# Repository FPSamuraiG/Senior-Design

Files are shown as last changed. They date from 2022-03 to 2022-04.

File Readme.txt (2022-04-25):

An Electronic Enrichment System for Saltwater Animal Enclosures

University of Cincinnati
CEAS
EE/ELTN Senior Design
April 2022

Team Members:
  Chris Dombrosky
  Brandon Carroll
  Nathaniel Collum
  Hayden Lampert

Advisors:
  Dr. Dieter Vanderelst
  Dr. Katie Kalafut
  
This repository contains code, PCB files, 3D models, and documentation for this senior design project.

3D Models: Contains 3D models for the project's pushbutton enclosure and wireless charging pad as .step files. Also contains .stl files for 3D printing these components.

Datasheets: Contains manufacturer datasheets for key project components.

PDB Files: Contains EAGLE files for the projects PCBs. Also contains an EAGLE library for custom components used on the PCBs, zipped gerber files for manufacturing additional copies, and component lists for the PCBs.

Release: Contains the .hex file for programming the microcontroller used in this project.

Senior_Design.X: MPLAB X IDE project folder for the microcontroller code. Can be opened as a project in MPLAB X IDE with MPLAB Code Configurator installed.

Project Abstract:

In this project, we designed a prototype input collection system for use in interactive electronic systems in saltwater animal enclosures. Increasing interactivity in enclosures has the potential to improve animal welfare and allow for research and behavior monitoring. Implementing an input device underwater is made difficult by the lack of premade input devices that function underwater, waterproofing requirements, and the ineffectiveness of wireless communication methods underwater. To address these challenges, we designed a prototype input system that includes a custom submersible pushbutton, fiber optic communication, wirelessly rechargeable battery, and extensive waterproofing features. This prototype functions as a pushbutton that can be installed underwater and connected to an Arduino through a fiber optic cable. It provides a tactile input for animals while maintaining safety by not exposing wires or electronics to water. Although it only functions as a pushbutton in its current state, this prototype was designed to be easy to use and easy to add additional sensors or input devices to. Overall, it meets the basic needs presented by our advisors while also making future work and improvements easier.

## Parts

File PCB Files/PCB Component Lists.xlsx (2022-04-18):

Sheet: Control PCB
Label | Description | Value | Package | Required?
C1 | Microcontroller decoupling capacitor | 0.1uF | 1206 SMD | Required
C2 | MCLR Pin Capacitor (See 4.3 of PIC18F16Q41 Datasheet) | 0.1uF | 1206 SMD | Required
C5 | Voltage regulator decoupling capacitor | 0.1uF | 1206 SMD | Required
C6 | Voltage regulator decoupling capacitor | 0.1uF | 1206 SMD | Required
D1 | Fiber Optic Transmitter (TOTX1350 or equivalent) | n/a | Unique | Required
J1 | Programming connector (0.1" Pitch 5 pin male header) | n/a | 0.1" Pitch TH | Required
J2 | I/O pin connector (0.1" Pitch 6 pin female header) | n/a | 0.1" Pitch TH | Optional
J3 | Battery connector (0.1" Pitch 6 pin female header) | n/a | 0.1" Pitch TH | Optional
J4 | I/O pin connector (0.1" Pitch 6 pin female header) | n/a | 0.1" Pitch TH | Optional
J5 | I/O pin connector (0.1" Pitch 5 pin female header) | n/a | 0.1" Pitch TH | Optional
JP1 | MCLR capacitor solder jumper (See 4.3 of PIC18F16Q41 Datasheet) | n/a | SMD | Required
R1 | MCLR pullup resistor (See 4.3 of PIC18F16Q41 Datasheet) | 10kΩ | 1206 SMD | Required
R2 | MCLR current limiting resistor (See 4.3 of PIC18F16Q41 Datasheet) | 470kΩ | 1206 SMD | Required
R3 | Fiber transmitter curent limiting resistor (See TOTX1353 datasheet) | 1kΩ | 1206 SMD | Required
R4 | I/O optional pullup resistor | 10kΩ | 1206 SMD | Optional
R5 | I/O optional pullup resistor | 10kΩ | 1206 SMD | Optional
R6 | I/O optional pullup resistor | 10kΩ | 1206 SMD | Optional
R7 | I/O optional pullup resistor | 10kΩ | 1206 SMD | Optional
R8 | Fuel gauge alert pullup resistor | 10kΩ | 1206 SMD | Optional
R9 | I2C SCL line pullup resistor | 2.2kΩ | 1206 SMD | Required
R10 | I2C SDA line pullup resistor | 2.2kΩ | 1206 SMD | Required
R11 | I/O optional pullup resistor | 10kΩ | 1206 SMD | Optional
R12 | I/O optional pullup resistor | 10kΩ | 1206 SMD | Optional
R13 | I/O optional pullup resistor | 10kΩ | 1206 SMD | Optional
R14 | I/O optional pullup resistor | 10kΩ | 1206 SMD | Optional
R15 | Reed switch pullup resistor | 10kΩ | 1206 SMD | Required
R16 | I/O optional pullup resistor | 10kΩ | 1206 SMD | Optional
R17 | I/O optional pullup resistor | 10kΩ | 1206 SMD | Optional
IC1 | PIC18F16Q41 microcontroller | n/a | 20 DIP/DIL | Required
U1 | AP2138N-3.3TRG1 linear voltage regulator (3.3V out) | n/a | SOT23-3 | Required

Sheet: Receiver PCB
Label | Description | Value | Package | Required?
U1 | Fiber Optic Receiver (TORX1355 or equivalent) | n/a | Unique | Required
U2 | Hex Inverter (SN74HC04 or equivalent) | n/a | PDIP-14 | Required
C1 | Capacitor | 0.1 uF | 1206 SMD | Required
J1 | Header (0.1" Pitch 5 pin female header) | n/a | 0.1" Pitch TH | Required

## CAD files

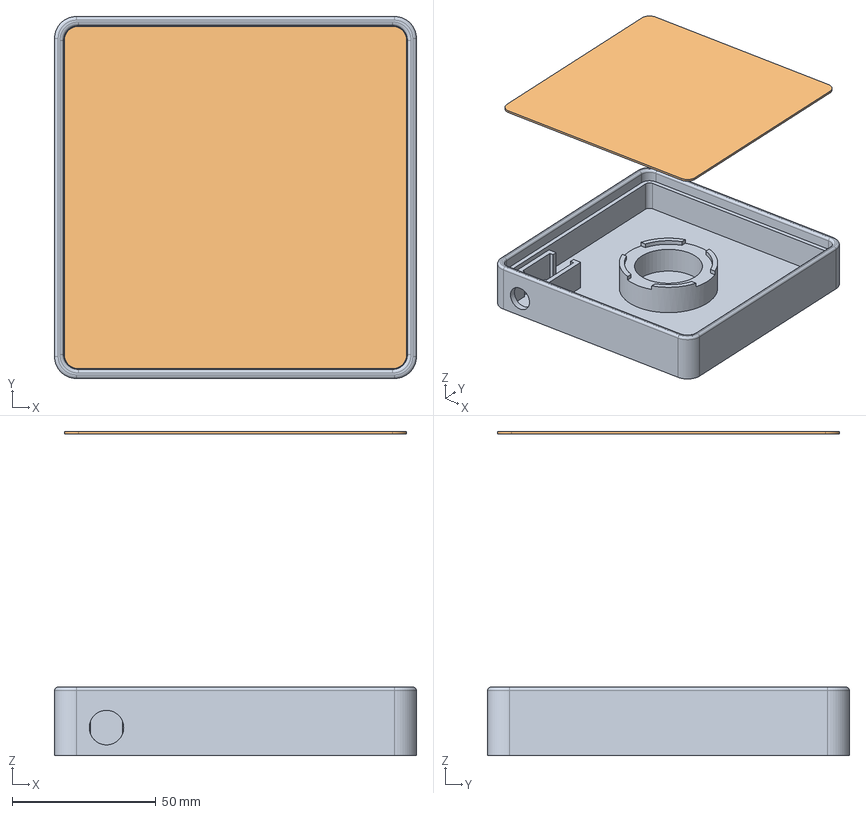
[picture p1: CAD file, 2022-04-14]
3D Models/Charging Tray.step
125.8 x 125.8 x 112.7 mm

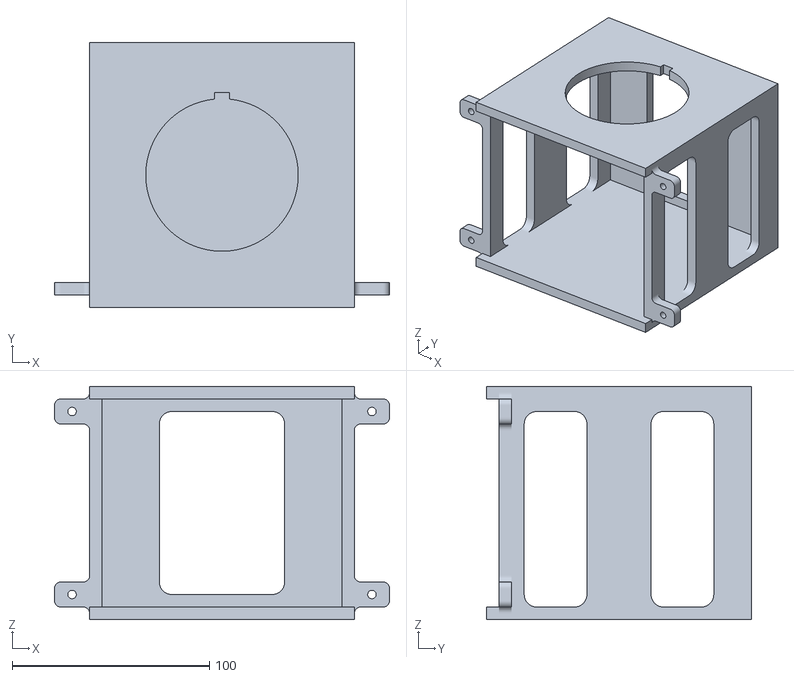
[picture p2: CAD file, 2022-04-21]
3D Models/STL Files/Shell.stl
169.7 x 134.1 x 118.1

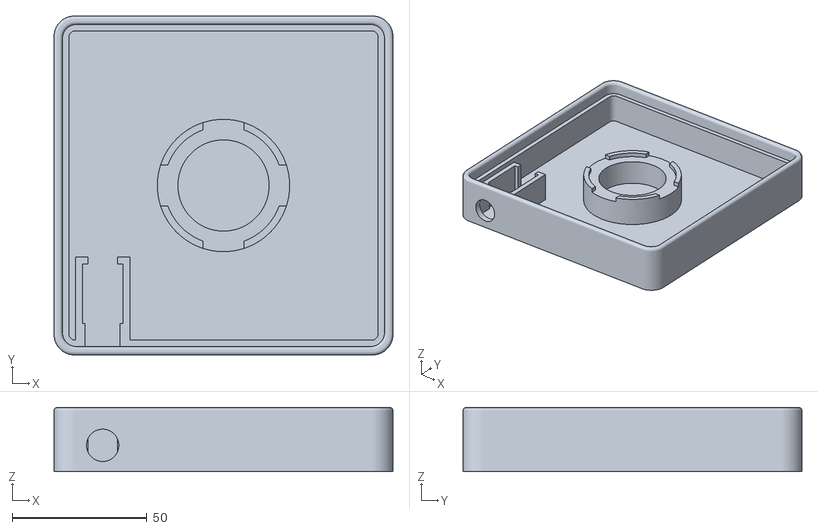
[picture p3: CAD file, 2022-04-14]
3D Models/STL Files/Tray.stl
125.8 x 125.8 x 23.9

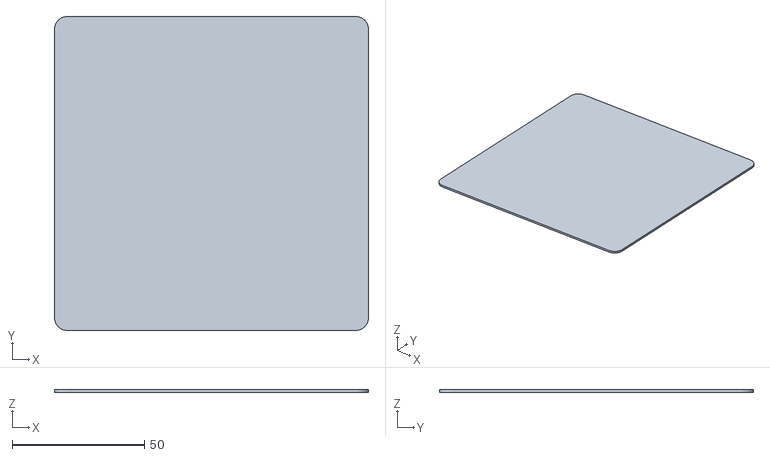
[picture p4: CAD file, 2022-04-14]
3D Models/STL Files/Plate.stl
118.9 x 118.9 x 1.00

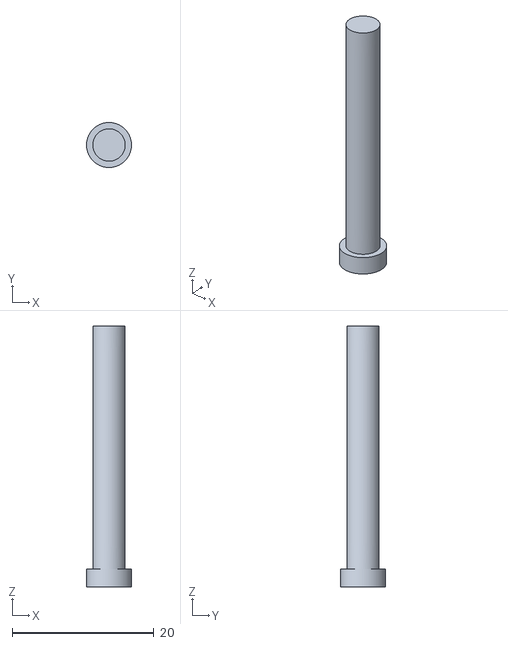
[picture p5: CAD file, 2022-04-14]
3D Models/STL Files/Spring Support.stl
6.35 x 6.35 x 36.8

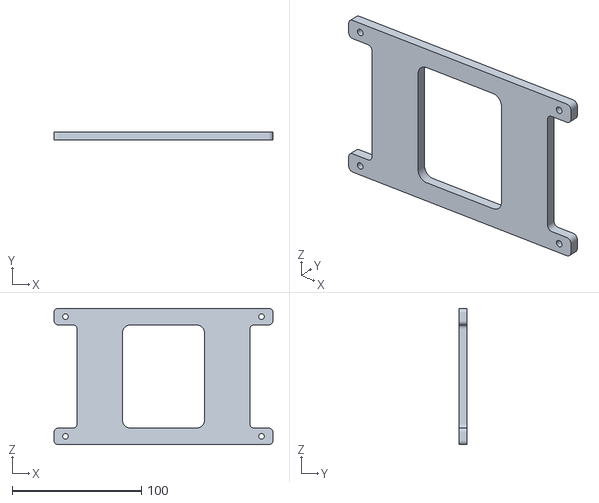
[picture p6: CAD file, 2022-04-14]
3D Models/STL Files/Wall.stl
169.7 x 6.35 x 105.4

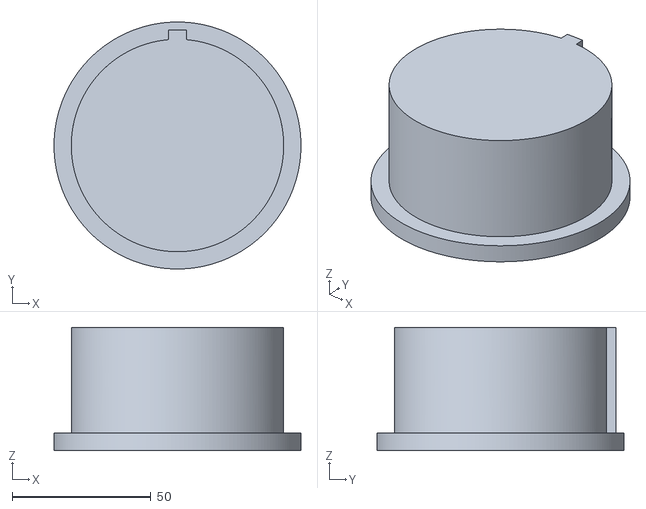
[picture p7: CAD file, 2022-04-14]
3D Models/STL Files/Button.stl
88.9 x 88.9 x 44.5

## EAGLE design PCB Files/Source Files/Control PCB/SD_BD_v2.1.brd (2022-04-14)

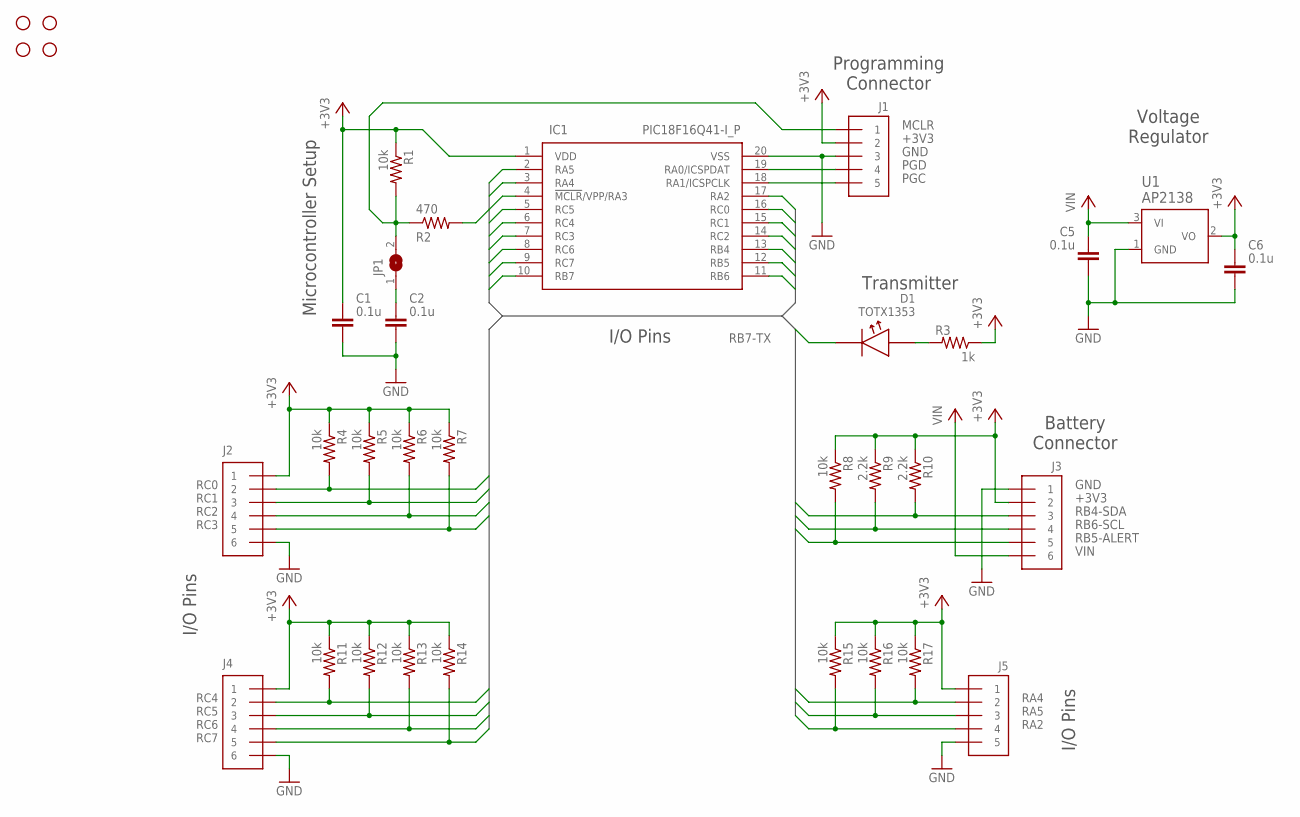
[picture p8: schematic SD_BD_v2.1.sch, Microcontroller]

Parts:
C1, C2, C5, C6: 0.1u; CAPC3216X135
D1: TOTX1353; TOXX1353
H1, H2, H3, H4: STAND-OFF
IC1: PIC18F16Q41-I_P; DIP794W56P254L2591H533Q20N
J1: M20-9990546; HDR-5-M
J2, J3, J4: PPTC061LFBN-RC; HDR-6-F
J5: PPTC051LFBN-RC; HDR-5-F
JP1: SJ
R1, R4, R5, R6, R7, R8, R11, R12, R13, R14, R15, R16, R17: 10k; R1206
R2: 470; R1206
R3: 1k; R1206
R9, R10: 2.2k; R1206
U1: AP2138N-3.3TRG1IC3_AP2138N-3.3TRG1_DIO-M; IC3_AP2138N-3.3TRG1_DIO-M

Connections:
+3V3: C1.1, C6.1, IC1.1 (VDD), J1.2, J2.1, J3.2, J4.1, J5.1, R1.1, R3.1, R4.1, R5.1, R6.1, R7.1, R8.1, R9.1, R10.1, R11.1, R12.1, R13.1, R14.1, R15.1, R16.1, R17.1, U1.2 (VO)
GND: C1.2, C2.2, C5.2, C6.2, IC1.20 (VSS), J1.3, J2.6, J3.1, J4.6, J5.5, U1.1 (GND)
MCLR: J1.1, JP1.2, R1.2, R2.1
unnamed: D1.3 (A), R3.2
unnamed: IC1.4 (!MCLR!/VPP/RA3), R2.2
unnamed: C2.1, JP1.1
PGC: IC1.18 (RA1/ICSPCLK), J1.5
PGD: IC1.19 (RA0/ICSPDAT), J1.4
RA2: IC1.17 (RA2), J5.4, R15.2
RA4: IC1.3 (RA4), J5.2, R17.2
RA5: IC1.2 (RA5), J5.3, R16.2
RB4-SDA: IC1.13 (RB4), J3.3, R10.2
RB5-ALERT: IC1.12 (RB5), J3.5, R8.2
RB6-SCL: IC1.11 (RB6), J3.4, R9.2
RB7-TX: D1.2 (K), IC1.10 (RB7)
RC0: IC1.16 (RC0), J2.2, R4.2
RC1: IC1.15 (RC1), J2.3, R5.2
RC2: IC1.14 (RC2), J2.4, R6.2
RC3: IC1.7 (RC3), J2.5, R7.2
RC4: IC1.6 (RC4), J4.2, R11.2
RC5: IC1.5 (RC5), J4.3, R12.2
RC6: IC1.8 (RC6), J4.4, R13.2
RC7: IC1.9 (RC7), J4.5, R14.2
VIN: C5.1, J3.6, U1.3 (VI)

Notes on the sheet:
I/O Pins
Transmitter
Microcontroller Setup
Voltage Regulator
Programming Connector
Battery Connector

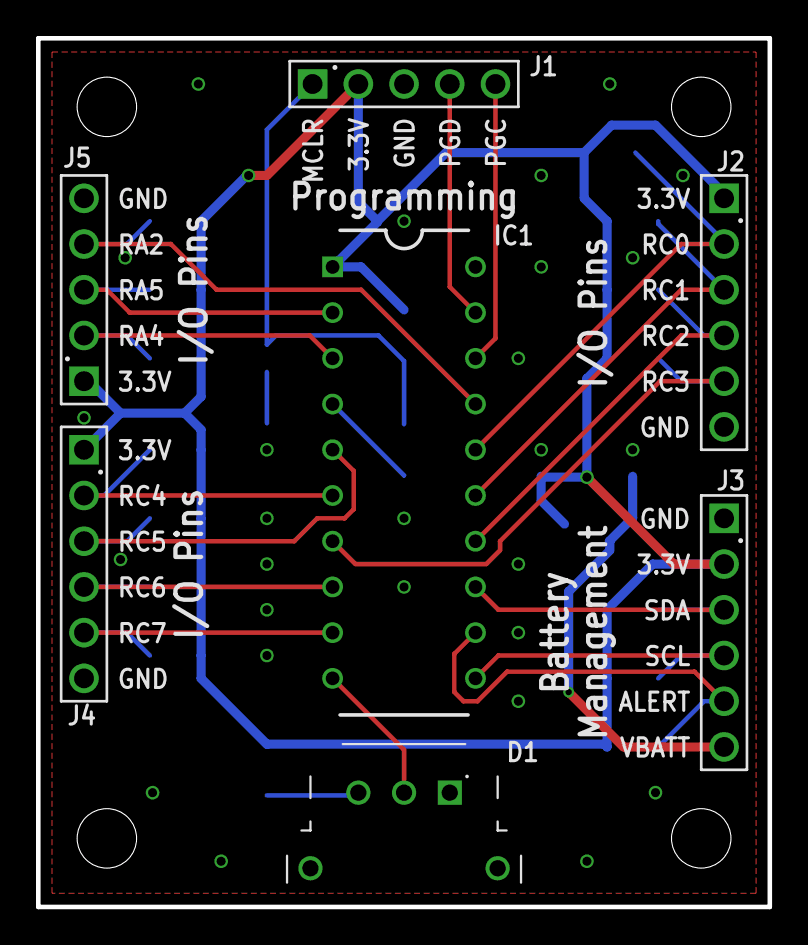
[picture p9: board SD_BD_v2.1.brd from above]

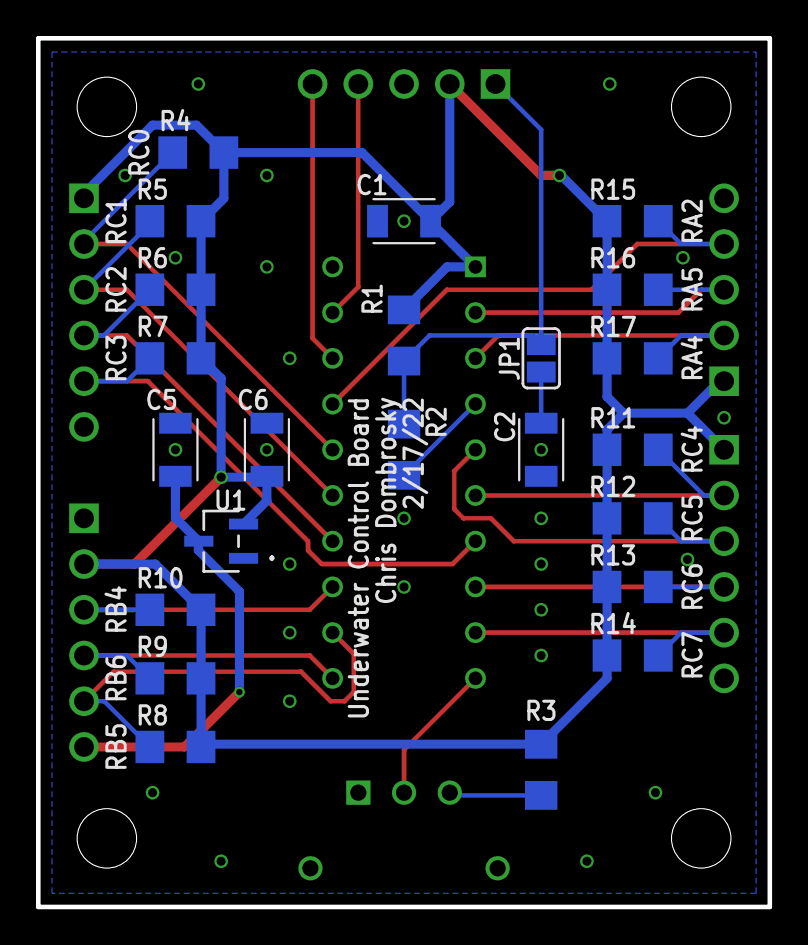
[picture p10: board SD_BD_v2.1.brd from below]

Board: 2 copper layers, 40.6 x 48.3 mm, 34 parts (23 on the bottom side), 24 nets.

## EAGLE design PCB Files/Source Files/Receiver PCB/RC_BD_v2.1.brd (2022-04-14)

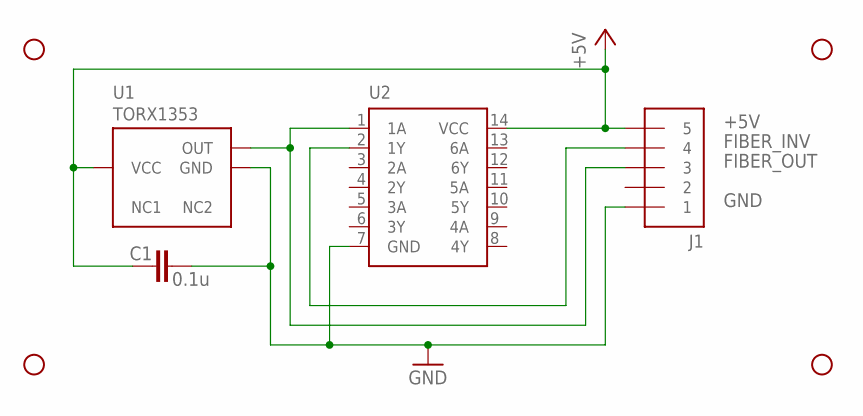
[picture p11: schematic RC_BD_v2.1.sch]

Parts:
C1: 0.1u; CAPC3216X135
H1, H2, H3, H4: STAND-OFF
J1: PPTC051LFBN-RC; HDR-5-F
U1: TORX1353; TOXX1353
U2: SN74HC04AN; DIL14

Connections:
+5V: C1.1, J1.5, U1.3 (VCC), U2.14 (VCC)
FIBER_INV: J1.4, U2.2 (1Y)
FIBER_OUT: J1.3, U1.1 (OUT), U2.1 (1A)
GND: C1.2, J1.1, U1.2 (GND), U2.7 (GND)

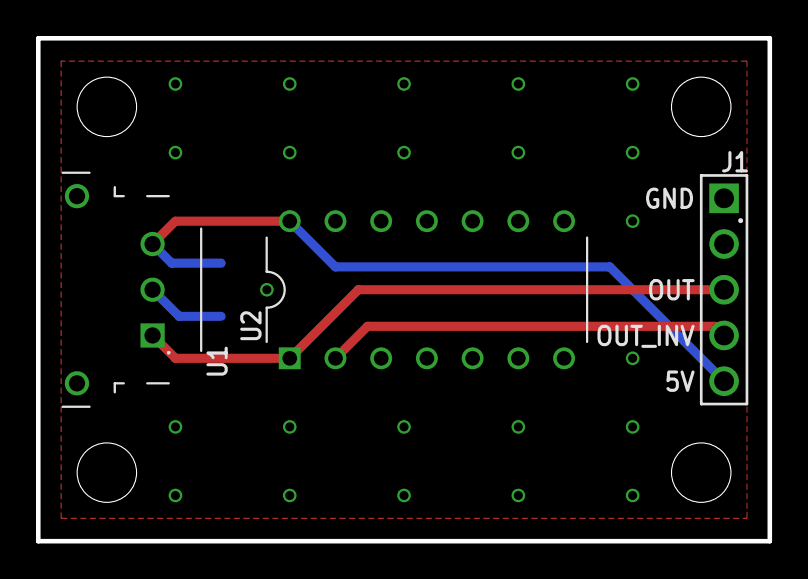
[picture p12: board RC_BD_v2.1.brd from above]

Board: 2 copper layers, 40.6 x 27.9 mm, 8 parts (1 on the bottom side), 4 nets.

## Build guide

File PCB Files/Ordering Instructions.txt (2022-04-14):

To Order Additional PCBs
	1) Upload zip files from the "Zipped Gerber Files" folder to JLCPCB
	2) Choose quantity and manufacturing options and order bare boards
	3) Order the electronic components listed in the "PCB Component Lists" spreadsheet
		3a) Order components from suppliers such as DigiKey or Mouser based on lowest price
		3b) For passives (resistors, capacitors) make sure to order the correct value and package for each component
		3c) For ICs and fiber optic components, order the same parts as in the spreadsheet if possible but choose an equivalent part based on data sheets if any component is unavailable
		3d) For headers only gender, number of pins, and pitch matter
	4) Receive components and solder

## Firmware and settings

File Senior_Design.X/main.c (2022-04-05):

/**
  Generated Main Source File

  Company:
    Microchip Technology Inc.

  File Name:
    main.c

  Summary:
    This is the main file generated using PIC10 / PIC12 / PIC16 / PIC18 MCUs

  Description:
    This header file provides implementations for driver APIs for all modules selected in the GUI.
    Generation Information :
        Product Revision  :  PIC10 / PIC12 / PIC16 / PIC18 MCUs - 1.81.7
        Device            :  PIC18F16Q41
        Driver Version    :  2.00
*/

/*
    (c) 2018 Microchip Technology Inc. and its subsidiaries. 
    
    Subject to your compliance with these terms, you may use Microchip software and any 
    derivatives exclusively with Microchip products. It is your responsibility to comply with third party 
    license terms applicable to your use of third party software (including open source software) that 
    may accompany Microchip software.
    
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
    IN NO EVENT WILL MICROCHIP BE LIABLE FOR ANY INDIRECT, SPECIAL, PUNITIVE, 
    INCIDENTAL OR CONSEQUENTIAL LOSS, DAMAGE, COST OR EXPENSE OF ANY KIND 
    WHATSOEVER RELATED TO THE SOFTWARE, HOWEVER CAUSED, EVEN IF MICROCHIP 
    HAS BEEN ADVISED OF THE POSSIBILITY OR THE DAMAGES ARE FORESEEABLE. TO 
    THE FULLEST EXTENT ALLOWED BY LAW, MICROCHIP'S TOTAL LIABILITY ON ALL 
    CLAIMS IN ANY WAY RELATED TO THIS SOFTWARE WILL NOT EXCEED THE AMOUNT 
    OF FEES, IF ANY, THAT YOU HAVE PAID DIRECTLY TO MICROCHIP FOR THIS 
    SOFTWARE.
*/

#include <stdio.h>
#include "mcc_generated_files/mcc.h"
#include "comm_uart.h"
#include "sleep.h"
#include "battery.h"

/*
                         Main application
 */
void main(void)
{
    // Initialize the device
    SYSTEM_Initialize();
    TMR0_StopTimer();
    sleep_setup();
    IOCAF2_SetInterruptHandler(btn_interrupt);
    TMR0_SetInterruptHandler(tmr_interrupt);
    INTERRUPT_GlobalInterruptEnable();
    
    //Startup procedure
    __delay_ms(100);
    uart_send_string("\nUnderwater Input Platform\r\n");
    uart_send_string("Version 0.20\t(3/6/2022)\r\n\n");
    
    int SOC; //Battery charge level;
 
    int start_btn_state; //State of pushbutton at start of loop, used to see if
                         //the button changed states during loop execution
    int last_btn_state_sent = 1;  //State of button when a message was last sent, used to
                             //avoid sending consecutive button states in situations
                             //like button bouncing.
    int btn_position = 0;
    
    char batt_msg[7]; //Battery message
    char btn_msg[7];  //Button message
    while (1)
    {
        //Save state of pushbutton at loop start
        __delay_ms(1);
        start_btn_state = btn_state;
        
        //Check if button is in same state after a delay to debounce
        __delay_ms(50);
        if(btn_state == start_btn_state) {
            input_handled = 1;
            
            //Don't send a new message if the button didn't change states from 
            //the last message sent (allow this behavior if the button is 
            //released to not miss a release message during erratic behavior)
            if (start_btn_state != last_btn_state_sent) {
                if (start_btn_state == 0) btn_position = 1;
                else btn_position = 0;

                snprintf(btn_msg, sizeof(btn_msg), "BTN0%i\r", btn_position);
                uart_send_string(btn_msg);
                last_btn_state_sent = start_btn_state;

                //Get battery charge level
                SOC = getsoc();

                //Construct battery status message
                if (SOC >= 0 && SOC < 10) snprintf(batt_msg, sizeof(batt_msg), "BAT0%i\r", SOC);
                else if (SOC >= 10 && SOC < 100) snprintf(batt_msg, sizeof(batt_msg), "BAT%i\r", SOC);
                else if (SOC == 100) snprintf(batt_msg, sizeof(batt_msg), "BAT00\r");
                else snprintf(batt_msg, sizeof(batt_msg), "BATER\r"); //Battery error

                //Only send battery level when button is pressed
                if(btn_position == 1) uart_send_string(batt_msg);
            }
        }
        
        //Only go to sleep if another interrupt didn't occur during the loop
        if(input_handled == 1) {
            if(last_btn_state_sent == 0) TMR0_StartTimer(); //start timer if button was pressed
            sleep_enter();
        }
    }
}
/**
 End of File
*/

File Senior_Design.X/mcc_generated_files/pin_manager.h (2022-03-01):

/**
  @Generated Pin Manager Header File

  @Company:
    Microchip Technology Inc.

  @File Name:
    pin_manager.h

  @Summary:
    This is the Pin Manager file generated using PIC10 / PIC12 / PIC16 / PIC18 MCUs

  @Description
    This header file provides APIs for driver for .
    Generation Information :
        Product Revision  :  PIC10 / PIC12 / PIC16 / PIC18 MCUs - 1.81.7
        Device            :  PIC18F16Q41
        Driver Version    :  2.11
    The generated drivers are tested against the following:
        Compiler          :  XC8 2.31 and above
        MPLAB 	          :  MPLAB X 5.45	
*/

/*
    (c) 2018 Microchip Technology Inc. and its subsidiaries. 
    
    Subject to your compliance with these terms, you may use Microchip software and any 
    derivatives exclusively with Microchip products. It is your responsibility to comply with third party 
    license terms applicable to your use of third party software (including open source software) that 
    may accompany Microchip software.
    
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
    IN NO EVENT WILL MICROCHIP BE LIABLE FOR ANY INDIRECT, SPECIAL, PUNITIVE, 
    INCIDENTAL OR CONSEQUENTIAL LOSS, DAMAGE, COST OR EXPENSE OF ANY KIND 
    WHATSOEVER RELATED TO THE SOFTWARE, HOWEVER CAUSED, EVEN IF MICROCHIP 
    HAS BEEN ADVISED OF THE POSSIBILITY OR THE DAMAGES ARE FORESEEABLE. TO 
    THE FULLEST EXTENT ALLOWED BY LAW, MICROCHIP'S TOTAL LIABILITY ON ALL 
    CLAIMS IN ANY WAY RELATED TO THIS SOFTWARE WILL NOT EXCEED THE AMOUNT 
    OF FEES, IF ANY, THAT YOU HAVE PAID DIRECTLY TO MICROCHIP FOR THIS 
    SOFTWARE.
*/

#ifndef PIN_MANAGER_H
#define PIN_MANAGER_H

/**
  Section: Included Files
*/

#include <xc.h>

#define INPUT   1
#define OUTPUT  0

#define HIGH    1
#define LOW     0

#define ANALOG      1
#define DIGITAL     0

#define PULL_UP_ENABLED      1
#define PULL_UP_DISABLED     0

// get/set btn aliases
#define btn_TRIS                 TRISAbits.TRISA2
#define btn_LAT                  LATAbits.LATA2
#define btn_PORT                 PORTAbits.RA2
#define btn_WPU                  WPUAbits.WPUA2
#define btn_OD                   ODCONAbits.ODCA2
#define btn_ANS                  ANSELAbits.ANSELA2
#define btn_SetHigh()            do { LATAbits.LATA2 = 1; } while(0)
#define btn_SetLow()             do { LATAbits.LATA2 = 0; } while(0)
#define btn_Toggle()             do { LATAbits.LATA2 = ~LATAbits.LATA2; } while(0)
#define btn_GetValue()           PORTAbits.RA2
#define btn_SetDigitalInput()    do { TRISAbits.TRISA2 = 1; } while(0)
#define btn_SetDigitalOutput()   do { TRISAbits.TRISA2 = 0; } while(0)
#define btn_SetPullup()          do { WPUAbits.WPUA2 = 1; } while(0)
#define btn_ResetPullup()        do { WPUAbits.WPUA2 = 0; } while(0)
#define btn_SetPushPull()        do { ODCONAbits.ODCA2 = 0; } while(0)
#define btn_SetOpenDrain()       do { ODCONAbits.ODCA2 = 1; } while(0)
#define btn_SetAnalogMode()      do { ANSELAbits.ANSELA2 = 1; } while(0)
#define btn_SetDigitalMode()     do { ANSELAbits.ANSELA2 = 0; } while(0)

// get/set RB4 procedures
#define RB4_SetHigh()            do { LATBbits.LATB4 = 1; } while(0)
#define RB4_SetLow()             do { LATBbits.LATB4 = 0; } while(0)
#define RB4_Toggle()             do { LATBbits.LATB4 = ~LATBbits.LATB4; } while(0)
#define RB4_GetValue()              PORTBbits.RB4
#define RB4_SetDigitalInput()    do { TRISBbits.TRISB4 = 1; } while(0)
#define RB4_SetDigitalOutput()   do { TRISBbits.TRISB4 = 0; } while(0)
#define RB4_SetPullup()             do { WPUBbits.WPUB4 = 1; } while(0)
#define RB4_ResetPullup()           do { WPUBbits.WPUB4 = 0; } while(0)
#define RB4_SetAnalogMode()         do { ANSELBbits.ANSELB4 = 1; } while(0)
#define RB4_SetDigitalMode()        do { ANSELBbits.ANSELB4 = 0; } while(0)

// get/set RB5 procedures
#define RB5_SetHigh()            do { LATBbits.LATB5 = 1; } while(0)
#define RB5_SetLow()             do { LATBbits.LATB5 = 0; } while(0)
#define RB5_Toggle()             do { LATBbits.LATB5 = ~LATBbits.LATB5; } while(0)
#define RB5_GetValue()              PORTBbits.RB5
#define RB5_SetDigitalInput()    do { TRISBbits.TRISB5 = 1; } while(0)
#define RB5_SetDigitalOutput()   do { TRISBbits.TRISB5 = 0; } while(0)
#define RB5_SetPullup()             do { WPUBbits.WPUB5 = 1; } while(0)
#define RB5_ResetPullup()           do { WPUBbits.WPUB5 = 0; } while(0)
#define RB5_SetAnalogMode()         do { ANSELBbits.ANSELB5 = 1; } while(0)
#define RB5_SetDigitalMode()        do { ANSELBbits.ANSELB5 = 0; } while(0)

// get/set RB6 procedures
#define RB6_SetHigh()            do { LATBbits.LATB6 = 1; } while(0)
#define RB6_SetLow()             do { LATBbits.LATB6 = 0; } while(0)
#define RB6_Toggle()             do { LATBbits.LATB6 = ~LATBbits.LATB6; } while(0)
#define RB6_GetValue()              PORTBbits.RB6
#define RB6_SetDigitalInput()    do { TRISBbits.TRISB6 = 1; } while(0)
#define RB6_SetDigitalOutput()   do { TRISBbits.TRISB6 = 0; } while(0)
#define RB6_SetPullup()             do { WPUBbits.WPUB6 = 1; } while(0)
#define RB6_ResetPullup()           do { WPUBbits.WPUB6 = 0; } while(0)
#define RB6_SetAnalogMode()         do { ANSELBbits.ANSELB6 = 1; } while(0)
#define RB6_SetDigitalMode()        do { ANSELBbits.ANSELB6 = 0; } while(0)

// get/set RB7 procedures
#define RB7_SetHigh()            do { LATBbits.LATB7 = 1; } while(0)
#define RB7_SetLow()             do { LATBbits.LATB7 = 0; } while(0)
#define RB7_Toggle()             do { LATBbits.LATB7 = ~LATBbits.LATB7; } while(0)
#define RB7_GetValue()              PORTBbits.RB7
#define RB7_SetDigitalInput()    do { TRISBbits.TRISB7 = 1; } while(0)
#define RB7_SetDigitalOutput()   do { TRISBbits.TRISB7 = 0; } while(0)
#define RB7_SetPullup()             do { WPUBbits.WPUB7 = 1; } while(0)
#define RB7_ResetPullup()           do { WPUBbits.WPUB7 = 0; } while(0)
#define RB7_SetAnalogMode()         do { ANSELBbits.ANSELB7 = 1; } while(0)
#define RB7_SetDigitalMode()        do { ANSELBbits.ANSELB7 = 0; } while(0)

/**
   @Param
    none
   @Returns
    none
   @Description
    GPIO and peripheral I/O initialization
   @Example
    PIN_MANAGER_Initialize();
 */
void PIN_MANAGER_Initialize (void);

/**
 * @Param
    none
 * @Returns
    none
 * @Description
    Interrupt on Change Handling routine
 * @Example
    PIN_MANAGER_IOC();
 */
void PIN_MANAGER_IOC(void);


/**
 * @Param
    none
 * @Returns
    none
 * @Description
    Interrupt on Change Handler for the IOCAF2 pin functionality
 * @Example
    IOCAF2_ISR();
 */
void IOCAF2_ISR(void);

/**
  @Summary
    Interrupt Handler Setter for IOCAF2 pin interrupt-on-change functionality

  @Description
    Allows selecting an interrupt handler for IOCAF2 at application runtime
    
  @Preconditions
    Pin Manager intializer called

  @Returns
    None.

  @Param
    InterruptHandler function pointer.

  @Example
    PIN_MANAGER_Initialize();
    IOCAF2_SetInterruptHandler(MyInterruptHandler);

*/
void IOCAF2_SetInterruptHandler(void (* InterruptHandler)(void));
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

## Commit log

2022-01-24 Adjusted some device and peripheral settings in MCC. Added source/header files for uart functions. Added a function to send a string over UART. Added a call to this function to main to use in testing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
2022-01-26 Updated code for test purposes. Modified main loop to turn on the built in LED on the dev board when the button is pressed.
2022-01-31 Added file for sleep mode related functions. Added second button to main loop for putting MCU into and out of sleep. Added interrupt on change to this button to send "BTN1" over UART when it is drive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
2022-02-09 Updated main loop to generate battery status messages based on charge level. Added source and header files for battery related functions
2022-02-22 Removed unnecessary i/o pins and uninverted uart polarity
2022-02-24 Added debounce to button interrupt.
2022-03-01 Removed weak pull ups (PCB will have external pullups) Removed newline characters from output strings. (End of message is indicated by carriage return \r)
2022-03-01 Changed button input from pin RC0 to RA2 as this is where the reed switch will be connected on the PCB.
2022-03-03 Added message for button release.
2022-03-06 Changed code so messages are only sent from the main loop in order to prevent the button interrupt from sending a message in the middle of the battery message.
    Added debouncing checks to main loop.
    [main.c]
2022-03-21 Slight changes to debounce behavior to not miss the button being released.
2022-03-23 Discovered that if the button is pressed and released quickly enough, the state change upon release will happen when the interrupt from the state change upon being pressed is being processed. This ca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
    Solution: Added a 1 second timer after entering sleep mode while the button is pressed. This timer triggers an interrupt that records the state of the button and halts the timer. This also wakes the 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
2022-03-23 Discovered that if the button is pressed and released quickly enough, the state change upon release will happen when the interrupt from the state change upon being pressed is being processed. This ca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
2022-04-14 Initial Commit of source and stl files for 3D printed components.
    [Button.stl, Charging Tray.step, Frame.stl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]
2022-04-14 Initial commit of source and gerber files for PCBs.
    [PCB Component Lists.xlsx, RC_BD_v2.1.brd, RC_BD_v2.1.sch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]
2022-04-18 Changed table theme to dark grey.
    [PCB Component Lists.xlsx]
2022-04-21 Replaced incorrect stl file with correct file.
    [Frame.stl, Shell.stl]

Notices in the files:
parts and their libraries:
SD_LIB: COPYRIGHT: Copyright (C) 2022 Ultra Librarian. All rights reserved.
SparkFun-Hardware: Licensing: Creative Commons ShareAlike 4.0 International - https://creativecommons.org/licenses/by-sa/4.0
